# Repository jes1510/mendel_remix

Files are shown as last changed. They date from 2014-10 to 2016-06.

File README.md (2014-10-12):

Designed by Jesse Merritt www.github.com/jes1510 October 12, 2014.

This program is free software: you can redistribute it and/or modify it under the terms of the GNU General Public License as published by the Free Software Foundation, either version 3 of the License, or (at your option) any later version.

This program is distributed in the hope that it will be useful, but WITHOUT ANY WARRANTY; without even the implied warranty of MERCHANTABILITY or FITNESS FOR A PARTICULAR PURPOSE. See the GNU General Public License for more details.

You should have received a copy of the GNU General Public License along with this program. If not, see <http://www.gnu.org/licenses/

Based heavily on the Mendelmax 2.0 and Prusa i3 reprap printers.  See www.reprap.org for more information

You can assume that I have no idea what I am doing and therefore am not responsible for any damage or negative consequences for using anything from this project. It may destroy all of your equipment and burn down your house.

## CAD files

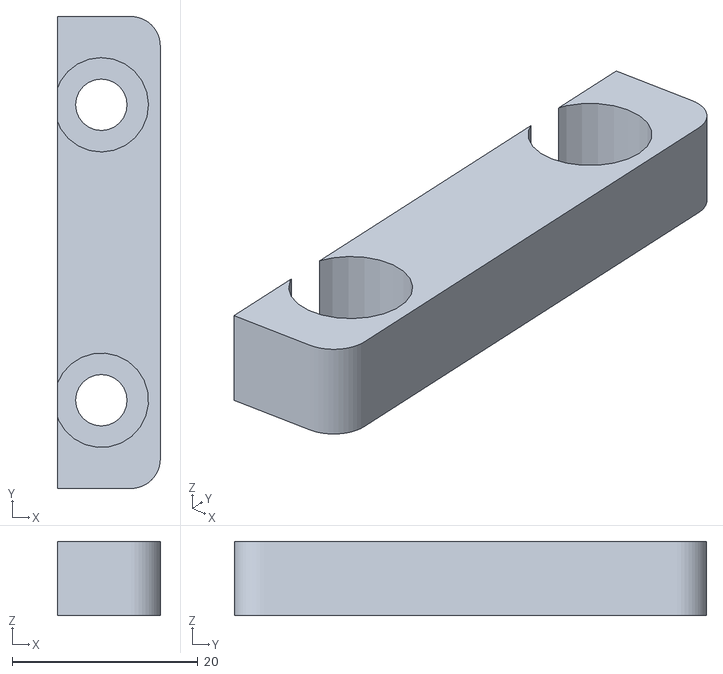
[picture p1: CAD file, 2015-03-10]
cc_spacer.stl
11.0 x 50.8 x 8.00

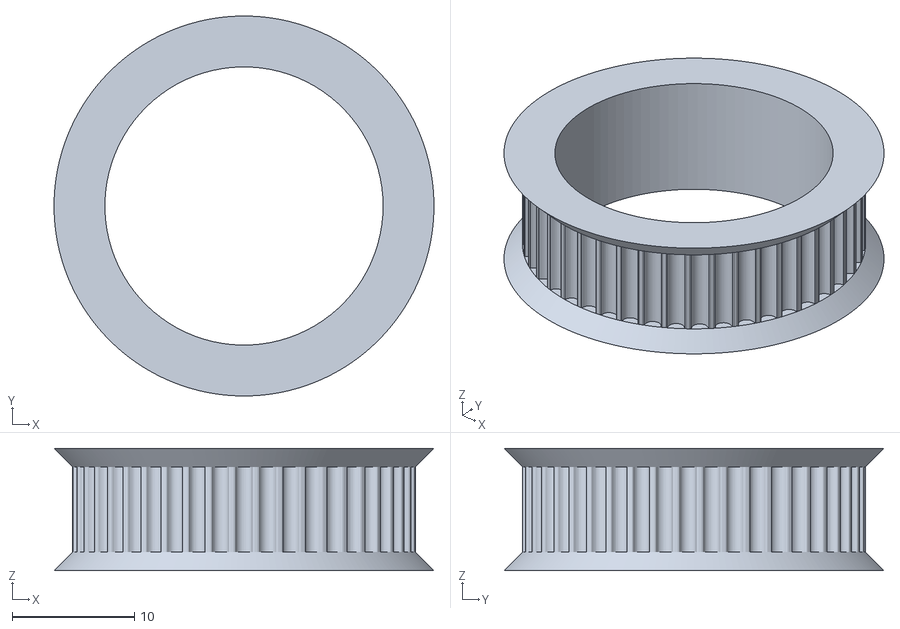
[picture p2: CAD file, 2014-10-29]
parts/2mm_GT2_idler_for_608zz_bearing/608ZZ_GT2_idler4.stl
31.1 x 31.1 x 10.0

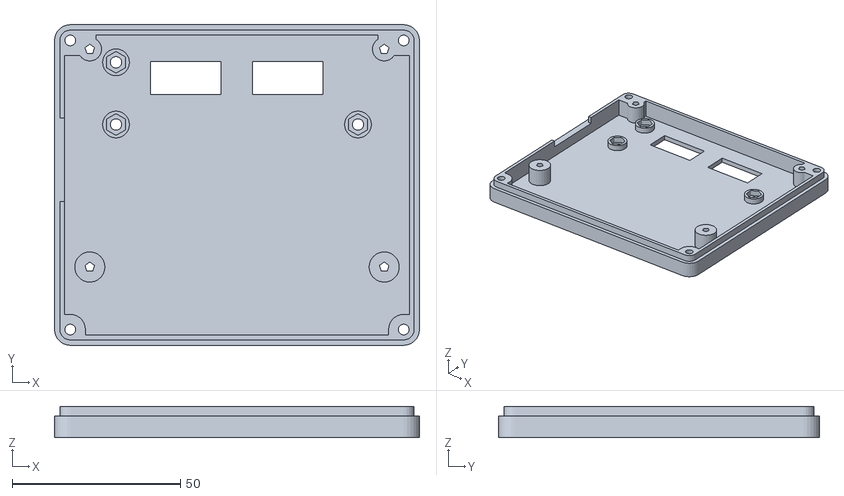
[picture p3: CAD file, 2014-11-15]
parts/3DR_-_RepRapDiscount_Full_Graphic_Smart_Controller_case/3DR_Pablo_LCD_case_bottom.stl
108.6 x 95.4 x 9.28

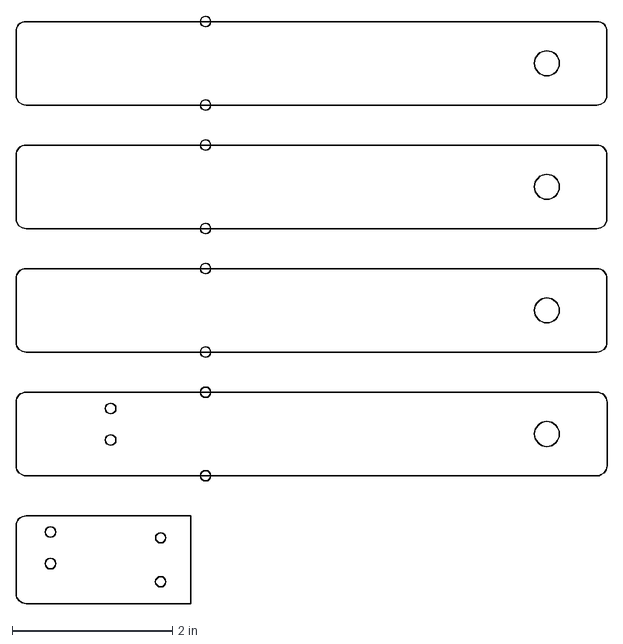
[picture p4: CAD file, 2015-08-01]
parts/bed_cablechain_brackets.dxf
7.37 x 7.33 in

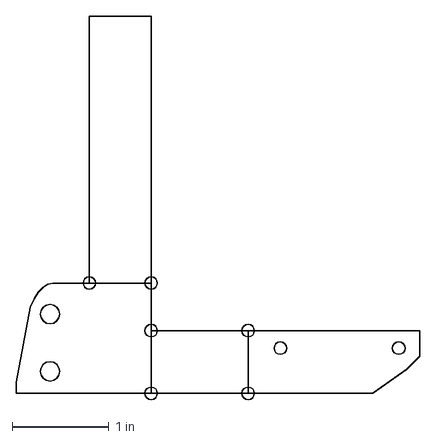
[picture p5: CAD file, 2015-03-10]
parts/Cable_Chain/cc_z_bracket.dxf
4.16 x 3.95 in

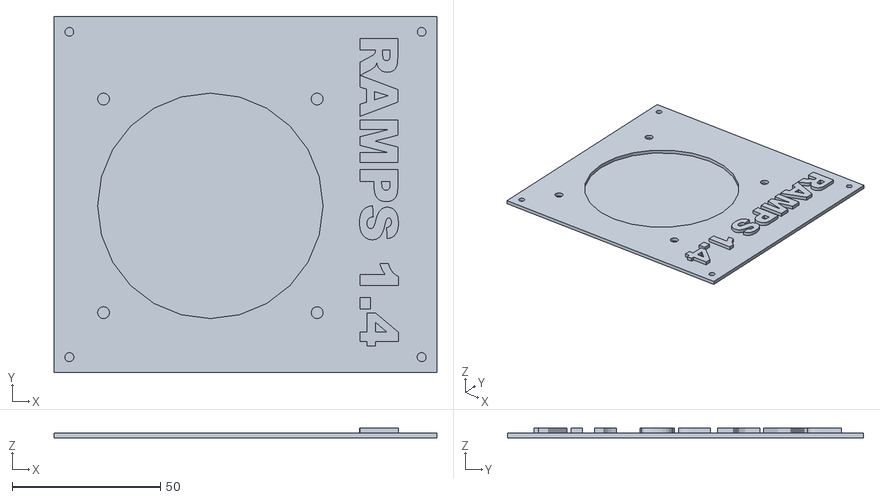
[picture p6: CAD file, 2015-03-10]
parts/case/Ramps_1.4_Mountable_Case/lid_fixed.stl
129.1 x 120.0 x 3.37

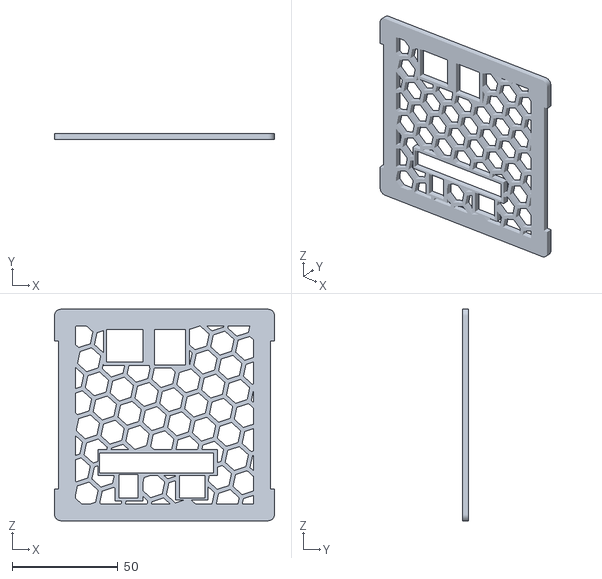
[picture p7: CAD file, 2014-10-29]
parts/electronics/Enclosure_RaspberryPi__ramps/Deckel_Front.STL
104.0 x 3.00 x 100.0

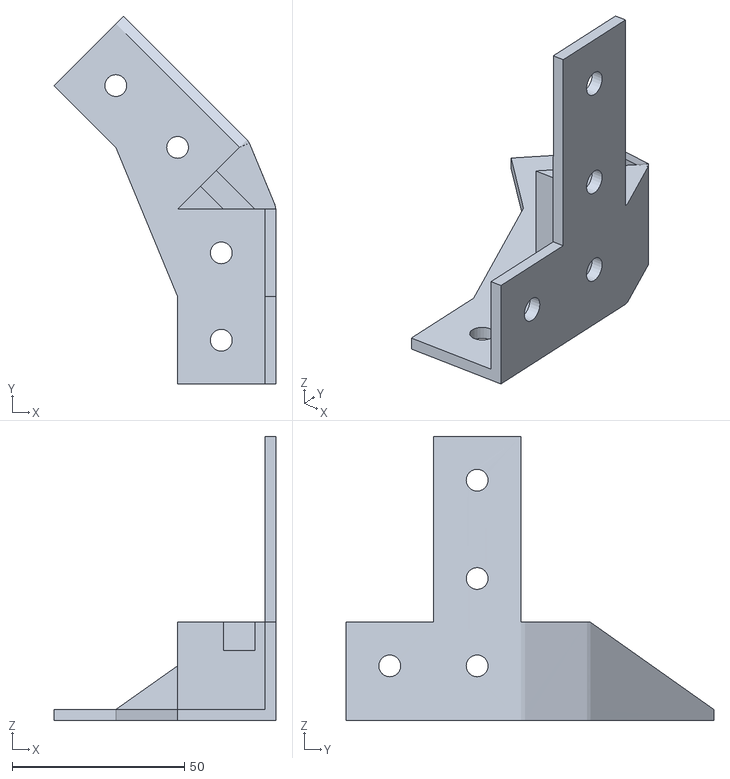
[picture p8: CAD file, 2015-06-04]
parts/enclosure/front_mid_brackets/front_mid_R_bracket_fixed.stl
64.5 x 106.9 x 82.6

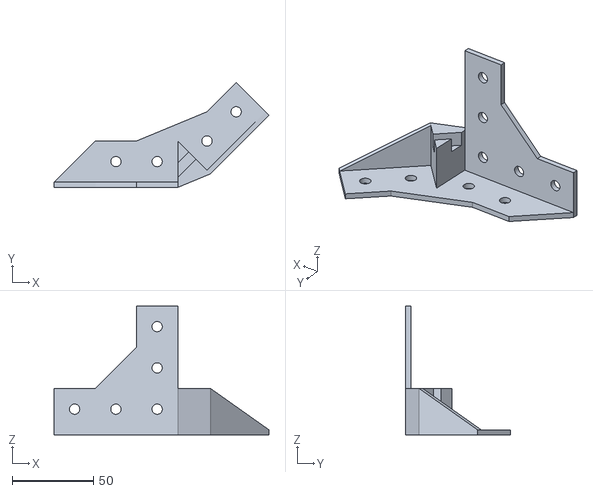
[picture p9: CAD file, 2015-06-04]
parts/enclosure/left_top_front.stl
132.3 x 64.5 x 79.4

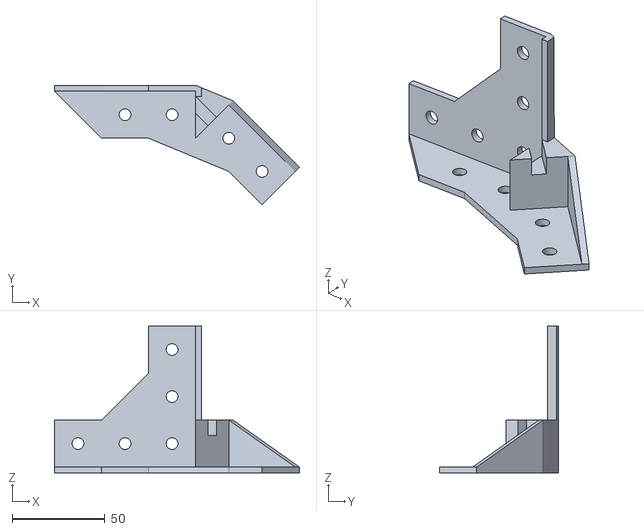
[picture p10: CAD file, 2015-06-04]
parts/enclosure/new_brackets/right_B.stl
132.3 x 64.5 x 79.4

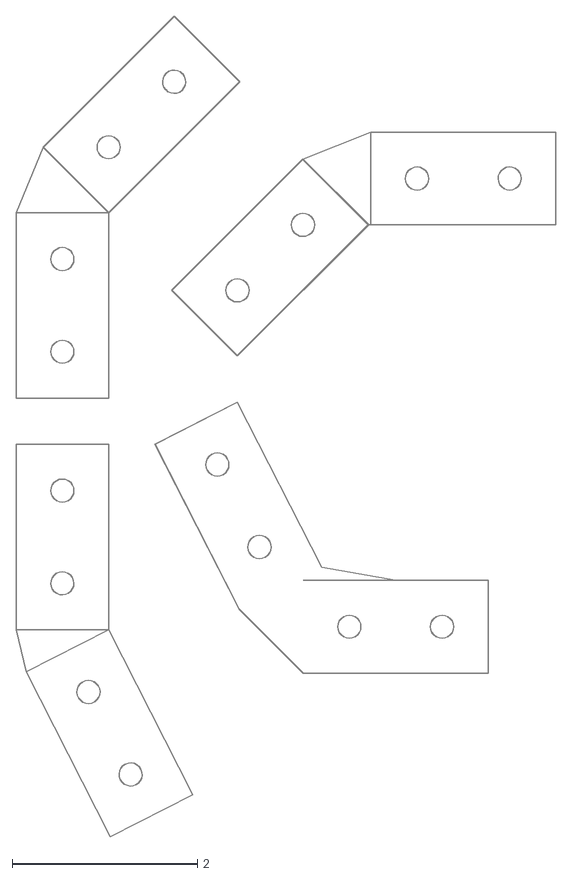
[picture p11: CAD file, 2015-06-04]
parts/enclosure/simple_brackets/simple_brackets.dxf
5.83 x 8.86

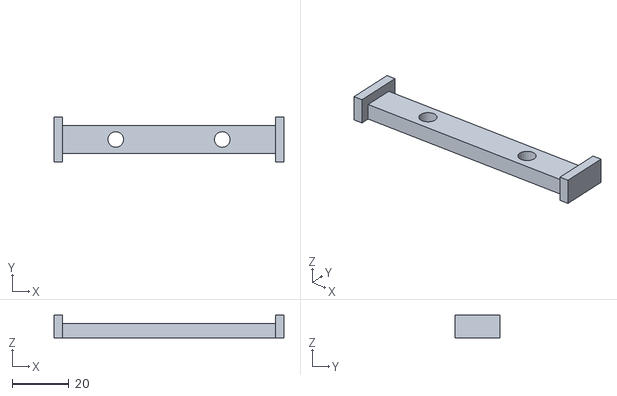
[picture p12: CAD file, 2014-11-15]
parts/lcd_support/support.stl
81.0 x 16.0 x 8.00

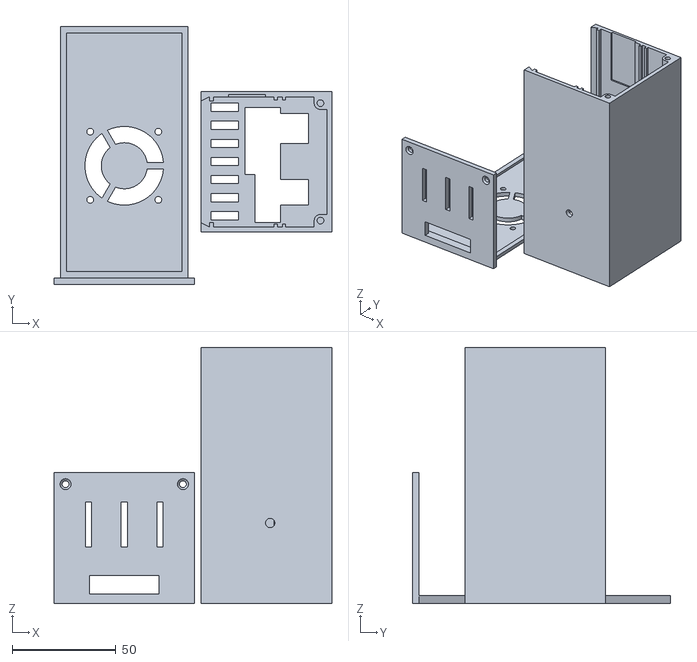
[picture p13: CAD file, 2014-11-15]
parts/RAMPS_14_Box_with_Smart_Adaptor/case-plate.stl
133.9 x 124.0 x 123.5

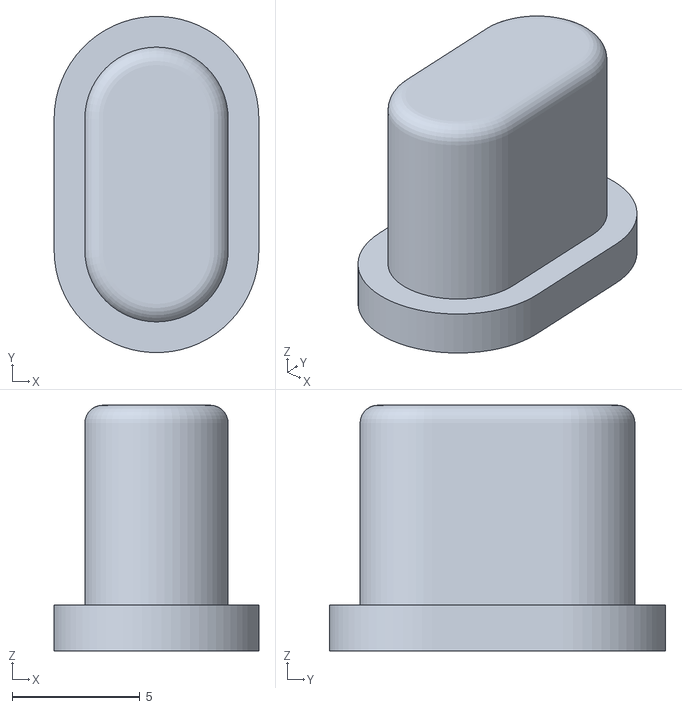
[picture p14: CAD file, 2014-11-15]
parts/3DR_-_RepRapDiscount_Full_Graphic_Smart_Controller_case/3DR_Pablo_LCD_button_kill.stl
8.00 x 13.1 x 9.60

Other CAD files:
parts/RAMP_14_Enclosure_Proven_to_fit/case_expanded.stl
parts/y_axis/y_tensioner.dxf
parts/Cable_Chain/cc_150x8.stl
parts/case/Ramps_1.4_Mountable_Case/case_b.stl
parts/2mm_GT2_idler_for_608zz_bearing/Pulley_T-MXL-XL-HTD-GT2_N-tooth.scad
parts/RAMP_14_Enclosure_Proven_to_fit/RAMPSCase.scad
59140_reedswitch.skp
8020_printer.skp
L_Bracket.dxf
L_Bracket.skp
Lbracket_support_nested.dxf
acme_bracket.skp
belt_clamp.skp
belt_clamp.stl
bottom_z_support.dxf
bottom_z_support.skp
bottom_z_support_left.dxf
brackets.dxf
brackets_b.dxf
endstop_brackets_nested.dxf
extruder_bracket.dxf
extruder_bracket_b.dxf
extruder_car_bc.skp
extruder_car_bc.stl
extruder_carriage.skp
extruder_carriage.stl
extruder_carriage_b.skp
extruder_carriage_b.stl
extruder_carriage_c_print.skp
extruder_carriage_c_print.stl
extrusion_bracker.skp
extrusion_brackeruntitled.dxf
fron_back_panels.dxf
front_back.skp
front_back_b.dxf
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

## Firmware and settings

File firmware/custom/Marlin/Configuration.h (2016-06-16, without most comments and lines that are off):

#define CONFIGURATION_H
#define STRING_VERSION_CONFIG_H __DATE__ " " __TIME__ // build date and time
#define STRING_CONFIG_H_AUTHOR "(none, default config)" // Who made the changes.
#define SERIAL_PORT 0
#define BAUDRATE 115200
#define MOTHERBOARD 33
#define EXTRUDERS 1
#define POWER_SUPPLY 1
#define TEMP_SENSOR_0 1
#define TEMP_SENSOR_1 0
#define TEMP_SENSOR_2 0
#define TEMP_SENSOR_BED 1
#define MAX_REDUNDANT_TEMP_SENSOR_DIFF 10
#define TEMP_RESIDENCY_TIME 10  // (seconds)
#define TEMP_HYSTERESIS 3       // (degC) range of +/- temperatures considered "close" to the target one
#define TEMP_WINDOW     1       // (degC) Window around target to start the residency timer x degC early.
#define HEATER_0_MINTEMP 5
#define HEATER_1_MINTEMP 5
#define HEATER_2_MINTEMP 5
#define BED_MINTEMP 5
#define HEATER_0_MAXTEMP 275
#define HEATER_1_MAXTEMP 275
#define HEATER_2_MAXTEMP 275
#define BED_MAXTEMP 150
#define PIDTEMP
#define BANG_MAX 255 // limits current to nozzle while in bang-bang mode; 255=full current
#define PID_MAX 255 // limits current to nozzle while PID is active (see PID_FUNCTIONAL_RANGE below); 255=full current
  #define PID_FUNCTIONAL_RANGE 10 // If the temperature difference between the target temperature and the actual temperature
  #define PID_INTEGRAL_DRIVE_MAX 255  //limit for the integral term
  #define K1 0.95 //smoothing factor within the PID
  #define PID_dT ((OVERSAMPLENR * 10.0)/(F_CPU / 64.0 / 256.0)) //sampling period of the temperature routine
  #define  DEFAULT_Kp 12.03
  #define  DEFAULT_Ki 0.43
  #define  DEFAULT_Kd 83.54
#define MAX_BED_POWER 255 // limits duty cycle to bed; 255=full current
#define PREVENT_DANGEROUS_EXTRUDE
#define PREVENT_LENGTHY_EXTRUDE
#define EXTRUDE_MINTEMP 170
#define EXTRUDE_MAXLENGTH (X_MAX_LENGTH+Y_MAX_LENGTH) //prevent extrusion of very large distances.
#define ENDSTOPPULLUPS // Comment this out (using // at the start of the line) to disable the endstop pullup resistors
  #define ENDSTOPPULLUP_XMAX
  #define ENDSTOPPULLUP_YMAX
  #define ENDSTOPPULLUP_ZMAX
  #define ENDSTOPPULLUP_XMIN
  #define ENDSTOPPULLUP_YMIN
  #define ENDSTOPPULLUP_ZMIN
const bool X_MIN_ENDSTOP_INVERTING = true; // set to true to invert the logic of the endstop.
const bool Y_MIN_ENDSTOP_INVERTING = true; // set to true to invert the logic of the endstop.
const bool Z_MIN_ENDSTOP_INVERTING = true; // set to true to invert the logic of the endstop.
const bool X_MAX_ENDSTOP_INVERTING = true; // set to true to invert the logic of the endstop.
const bool Y_MAX_ENDSTOP_INVERTING = true; // set to true to invert the logic of the endstop.
const bool Z_MAX_ENDSTOP_INVERTING = true; // set to true to invert the logic of the endstop.
#if defined(COREXY) && !defined(DISABLE_MAX_ENDSTOPS)
  #define DISABLE_MAX_ENDSTOPS
#endif
#define X_ENABLE_ON 0
#define Y_ENABLE_ON 0
#define Z_ENABLE_ON 0
#define E_ENABLE_ON 0 // For all extruders
#define DISABLE_X false
#define DISABLE_Y false
#define DISABLE_Z false
#define DISABLE_E false // For all extruders
#define DISABLE_INACTIVE_EXTRUDER true //disable only inactive extruders and keep active extruder enabled
#define INVERT_X_DIR false    // for Mendel set to false, for Orca set to true
#define INVERT_Y_DIR false    // for Mendel set to true, for Orca set to false
#define INVERT_Z_DIR true     // for Mendel set to false, for Orca set to true
#define INVERT_E0_DIR false   // for direct drive extruder v9 set to true, for geared extruder set to false
#define INVERT_E1_DIR false    // for direct drive extruder v9 set to true, for geared extruder set to false
#define INVERT_E2_DIR false   // for direct drive extruder v9 set to true, for geared extruder set to false
#define X_HOME_DIR 1      // was -1
#define Y_HOME_DIR 1
#define Z_HOME_DIR -1
#define min_software_endstops false // If true, axis won't move to coordinates less than HOME_POS.
#define max_software_endstops true  // If true, axis won't move to coordinates greater than the defined lengths below.
#define X_MAX_POS 304.8
#define X_MIN_POS 0
#define Y_MAX_POS 304.8
#define Y_MIN_POS 0
#define Z_MAX_POS 170
#define Z_MIN_POS 0
#define X_MAX_LENGTH (X_MAX_POS - X_MIN_POS)
#define Y_MAX_LENGTH (Y_MAX_POS - Y_MIN_POS)
#define Z_MAX_LENGTH (Z_MAX_POS - Z_MIN_POS)
#define ENABLE_AUTO_BED_LEVELING // Delete the comment to enable (remove // at the start of the line)
#define Z_PROBE_REPEATABILITY_TEST  // If not commented out, Z-Probe Repeatability test will be included if Auto Bed Leveling is Enabled.
  #define AUTO_BED_LEVELING_GRID
    #define LEFT_PROBE_BED_POSITION 20      // 15
    #define RIGHT_PROBE_BED_POSITION 270    // 170
    #define BACK_PROBE_BED_POSITION 175    // 180
    #define FRONT_PROBE_BED_POSITION 0     // 20
    #define AUTO_BED_LEVELING_GRID_POINTS 3
  #define X_PROBE_OFFSET_FROM_EXTRUDER -36
  #define Y_PROBE_OFFSET_FROM_EXTRUDER -40
  #define Z_PROBE_OFFSET_FROM_EXTRUDER -11.85 // Was 11.35
  #define Z_RAISE_BEFORE_HOMING 10      // (in mm) Raise Z before homing (G28) for Probe Clearance.
  #define XY_TRAVEL_SPEED 8000         // X and Y axis travel speed between probes, in mm/min
  #define Z_RAISE_BEFORE_PROBING 15    //How much the extruder will be raised before traveling to the first probing point.
  #define Z_RAISE_BETWEEN_PROBINGS 5  //How much the extruder will be raised when traveling from between next probing points
#define PROBE_SERVO_DEACTIVATION_DELAY 500
#define Z_SAFE_HOMING   // This feature is meant to avoid Z homing with probe outside the bed area.
    #define Z_SAFE_HOMING_X_POINT (X_MAX_LENGTH/2)    // X point for Z homing when homing all axis (G28)
    #define Z_SAFE_HOMING_Y_POINT (Y_MAX_LENGTH/2)    // Y point for Z homing when hooming all axis (G28)
#define MANUAL_X_HOME_POS 0
#define MANUAL_Y_HOME_POS 0
#define MANUAL_Z_HOME_POS 0
#define NUM_AXIS 4 // The axis order in all axis related arrays is X, Y, Z, E
#define HOMING_FEEDRATE {50*60, 50*60, 4*60, 0}  // set the homing speeds (mm/min)
#define DEFAULT_AXIS_STEPS_PER_UNIT   {39.024, 39.024, 400, 104.32355}  // Z was 415.07749
#define DEFAULT_MAX_FEEDRATE          {500, 250, 5, 25}    // (mm/sec)
#define DEFAULT_MAX_ACCELERATION      {2000,1000,100,10000}    // X, Y, Z, E maximum start speed for accelerated moves. E default values are good for Skeinforge 40+, for older versions raise them a lot.
#define DEFAULT_ACCELERATION          1500    // X, Y, Z and E max acceleration in mm/s^2 for printing moves
#define DEFAULT_RETRACT_ACCELERATION  1500   // X, Y, Z and E max acceleration in mm/s^2 for retracts
#define DEFAULT_XYJERK                1.0    // (mm/sec)
#define DEFAULT_ZJERK                 0.4     // (mm/sec)
#define DEFAULT_EJERK                 1.0    // (mm/sec)
#define CUSTOM_M_CODES
  #define CUSTOM_M_CODE_SET_Z_PROBE_OFFSET 851
  #define Z_PROBE_OFFSET_RANGE_MIN -15
  #define Z_PROBE_OFFSET_RANGE_MAX -5
#define EEPROM_SETTINGS
#define EEPROM_CHITCHAT
#define PLA_PREHEAT_HOTEND_TEMP 190
#define PLA_PREHEAT_HPB_TEMP 60
#define PLA_PREHEAT_FAN_SPEED 255   // Insert Value between 0 and 255
#define ABS_PREHEAT_HOTEND_TEMP 225
#define ABS_PREHEAT_HPB_TEMP 110
#define ABS_PREHEAT_FAN_SPEED 0   // Insert Value between 0 and 255
#define REPRAP_DISCOUNT_FULL_GRAPHIC_SMART_CONTROLLER
 #define DOGLCD
 #define U8GLIB_ST7920
 #define REPRAP_DISCOUNT_SMART_CONTROLLER
 #define ULTIPANEL
 #define NEWPANEL
  #define SDSUPPORT
  #define ULTRA_LCD
    #define LCD_WIDTH 20
    #define LCD_HEIGHT 5
#  define DEFAULT_LCD_CONTRAST 32
#define TEMP_STAT_LEDS
#define SOFT_PWM_SCALE 1
#define RS_LIGHTS
#define RSLIGHTPIN 4
#define RSLIGHTPORT PORTF
#define NUM_SERVOS 3 // Servo index starts with 0 for M280 command
#define SERVO_ENDSTOPS {-1, -1, 0} // Servo index for X, Y, Z. Disable with -1
#define SERVO_ENDSTOP_ANGLES {0,0, 0,0, 100, 20} // X,Y,Z Axis Extend and Retract angles
#define FILAMENT_SENSOR
#define FILAMENT_SENSOR_EXTRUDER_NUM	0  //The number of the extruder that has the filament sensor (0,1,2)
#define MEASUREMENT_DELAY_CM			14  //measurement delay in cm.  This is the distance from filament sensor to middle of barrel
#define DEFAULT_NOMINAL_FILAMENT_DIA  3.0  //Enter the diameter (in mm) of the filament generally used (3.0 mm or 1.75 mm) - this is then used in the slicer software.  Used for sensor reading validation
#define MEASURED_UPPER_LIMIT          3.30  //upper limit factor used for sensor reading validation in mm
#define MEASURED_LOWER_LIMIT          1.90  //lower limit factor for sensor reading validation in mm
#define MAX_MEASUREMENT_DELAY			20  //delay buffer size in bytes (1 byte = 1cm)- limits maximum measurement delay allowable (must be larger than MEASUREMENT_DELAY_CM  and lower number saves RAM)
#define DEFAULT_MEASURED_FILAMENT_DIA  DEFAULT_NOMINAL_FILAMENT_DIA  //set measured to nominal initially
#include "Configuration_adv.h"
#include "thermistortables.h"

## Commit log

2014-10-12 Testing STL viewer by exporting entire printer as STL
2014-10-12 Added PC power supply realigned extruder carriage to be on center of Y-axis
2014-10-12 Added cutouts for power supply Added cutouts for rod mounts Added switch panel
2014-10-16 Changed to standard slide sizes added drills to table fixed clearance holes in y motor bracket
2014-10-25 Added bracket to extruder Added spacers on bed corrected gantry position removed bearings on Z
2014-10-29 Added parts to build
    [1515_1.skp, 1515_3.skp, 1515_5.skp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]
2014-10-29 Exported newest model STL Added autoleveling arm
2014-10-29 Moved entire model STL to root dir
2014-11-03 Various CAD improvements Added firmware
    [foot_cover.stl]
2014-11-15 added RAMPS case added cable chain Started cable chain attachment brackets
    [3D Printer Build Volume.skp, 3DR_Pablo_LCD_adapter.stl, 3DR_Pablo_LCD_button_big.stl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]
2015-01-13 Moved to heavier X cable carrier
    [1515_1.skp, 1515_3.skp, 1515_5.skp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]
2015-03-10 Removed all backup files (*~) Added cable chain to bed axis for heated bed Added cable chain brackets to bed axis
    [40mm_fab_extruder_bracket.dxf, 40mm_fab_extruder_bracket.skp, Ramps_1.4_Mountable_Case06966831b87491ca3ae4c1595dea0038-Ramps_box_1-3_fan_cover.stl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]
2015-03-18 Added firmware
    [Configuration.h, Configuration_adv.h, Menu Plans.xlsx]
2015-06-03 Added enclosure built out of 8020 - 1010 series Front and door are polycarbinate top and sides 1/4" mdf
    Changed z offset in firmware
    [Configuration.h]
2015-06-04 Added enclosure built from 8020
    [1010_end_cutout.dxf, L_Bracket.dxf, L_Bracket.skp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]
2015-08-01 Further refinements on enclosure
    [Configuration.h, bed_cablechain_brackets.dxf]
2016-02-22 Added Radio strip lights to firmware Modified enclosure
    [Configuration.h]
2016-06-16 Firmware update for lights
    [Configuration.h]
